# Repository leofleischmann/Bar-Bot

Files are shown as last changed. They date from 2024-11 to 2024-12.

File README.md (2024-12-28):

# Bar-Bot
Automatic Cocktail Maker (Work in Progress)

Project startet on 17th November 2024

This is my take on the Automatic Bartender Robot (original: https://github.com/sidlauskaslukas/barbot/tree/master?tab=readme-ov-file)

# Details
- You can freely decide which drink you want to put on which position. Then you can configure the drink and location in the webserver. (/config)
- You can easily create new recipes and manage your existing ones. (/rezepte)
- You can decide what drink is made with a click of a button. The available recipes are shown in green, while the other ones are red. You can see details on why a recipe is not available.
- Additionally you can see the contents of a recipe with the "?" icon
- Chancing location of drinks is as easy as it gets. Just set the name of your drink and the position.
- Adding new recipes is also very easy. Just select the drink and the quantity, and a file with the instructions for the esp is automatically created.
- When Bottles are reordered, it still works perfectly, as long as you define the new locations on the /config page

# Technical Details
The ESP has minimal code on it. It only takes 2 commands.
- move to position x and
- activate servo, hold for x ms, then go back
The Raspberry Pi takes the heavy lifting, by sending the right commands to the ESP

# Already done:
- All parts are assembled (except liquor holding and pouring construction)
- Project almost compleately digitalized for easyer testing, troubleshooting ect. (3D files, ESP32 emulators...)
- Raspberry Pi Server programmed and functional
- ESP32 Code functional and taking commands from the Raspberry Pi
- Basic Web-Interface for testing purposes.
- Software for the Raspberry Pi and ESP32
- Hardware testing
- Parameter tuning
- User Interface
- Fully functional Web interface to configure, edit, add, remove recipes and drinks with ther corresponding position
- (Done at 22th November 2024)

# Currently working on:
- Woodwork
- Final Adjustments

# Total Hardware cost (not including 3D printing material): to much

# Here are a few images
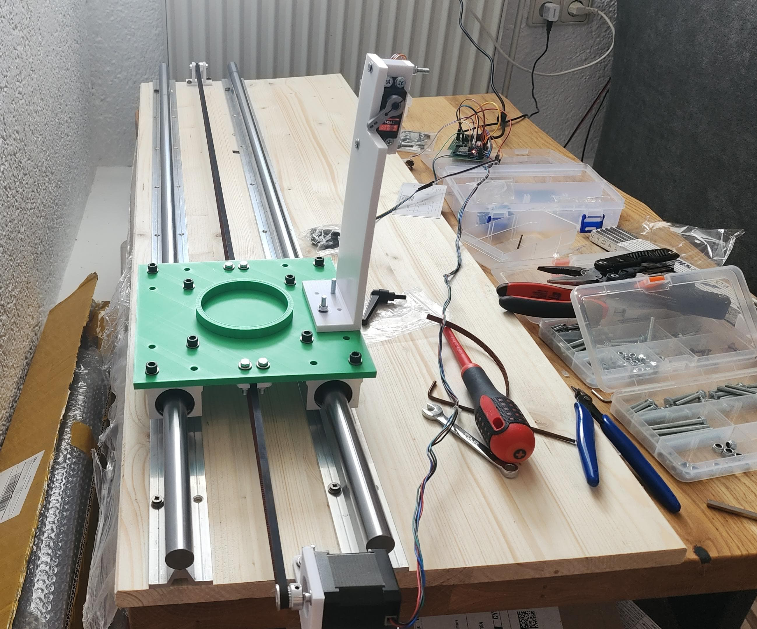
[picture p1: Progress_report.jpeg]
As of 22th November 2024

As of 22th November 2024

# Installation on the Raspberry Pi
- Simply copy the Repo on your Raspberry Pi
- Make sure Port 5001 and 5002 are not in use
- Create a service that starts the server.py script automatically
- You can now find the webserver on port 5001.
- When no Wifi is enabled, a HotSpot is created named "barbot" with password "12345678". You can connect and then configure a new Wifi on Port 5002.
- Have Fun :)

# About the Website:
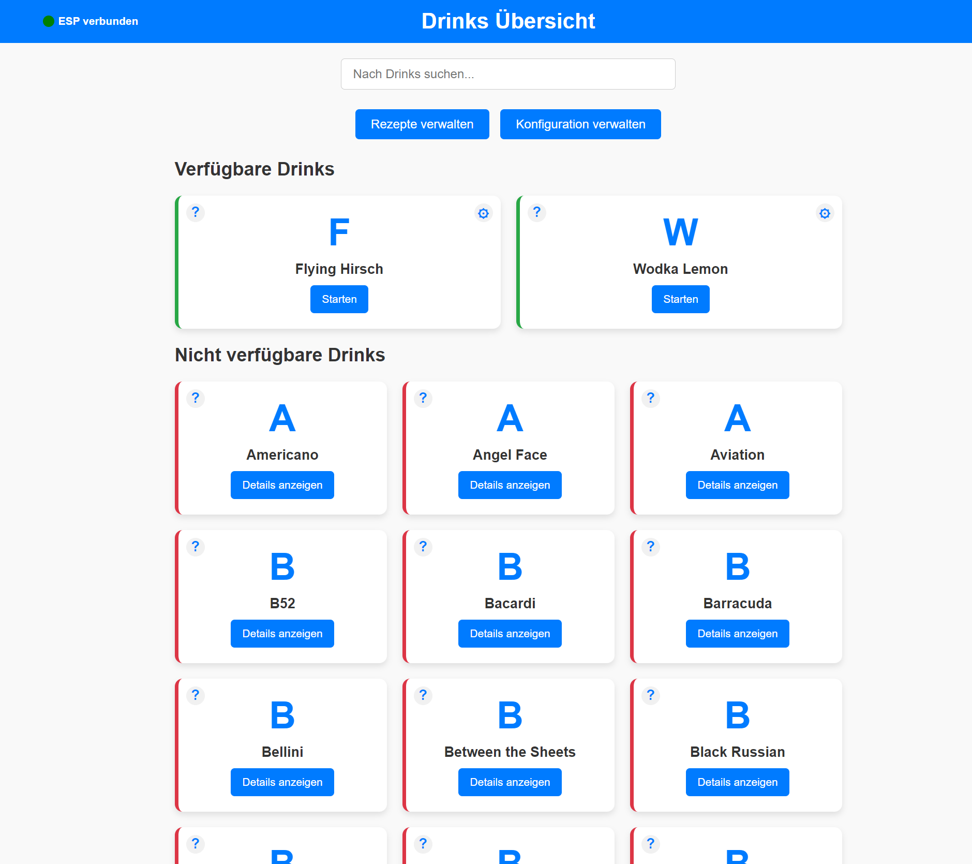
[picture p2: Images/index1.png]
index1.html

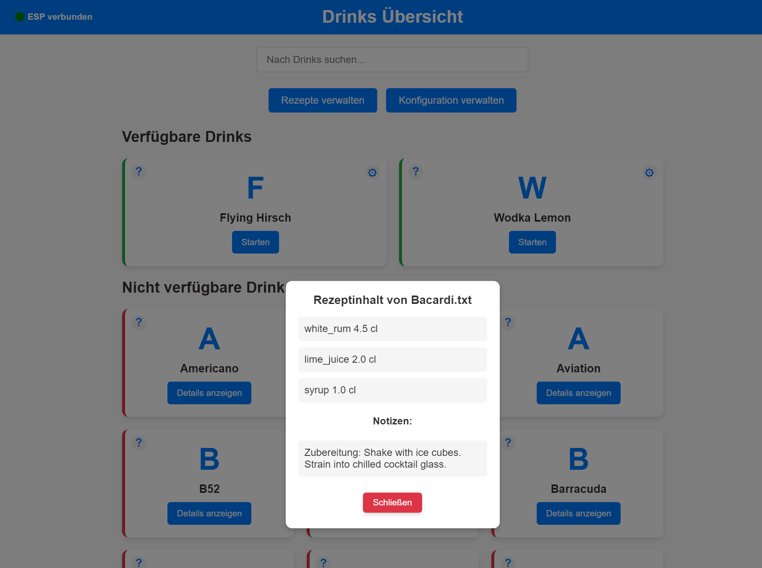
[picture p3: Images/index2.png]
index2.html

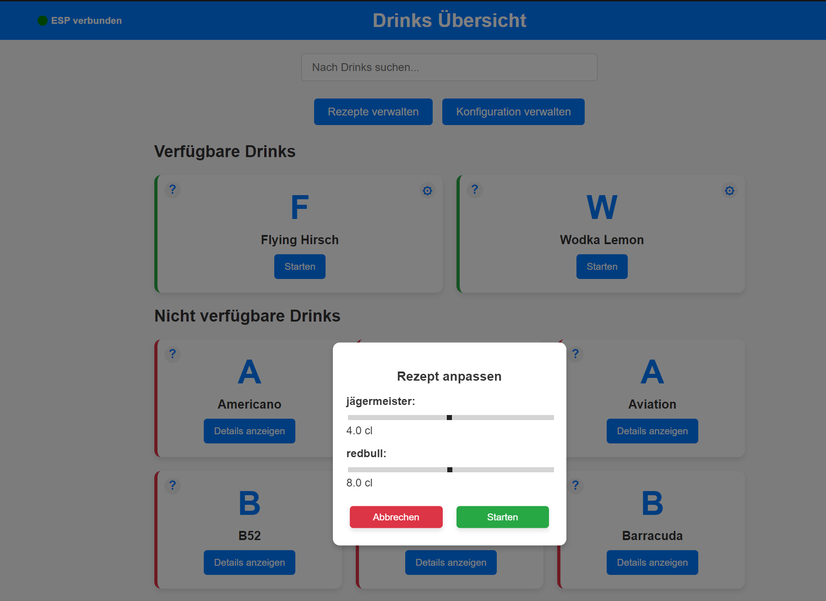
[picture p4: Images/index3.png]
index3.html

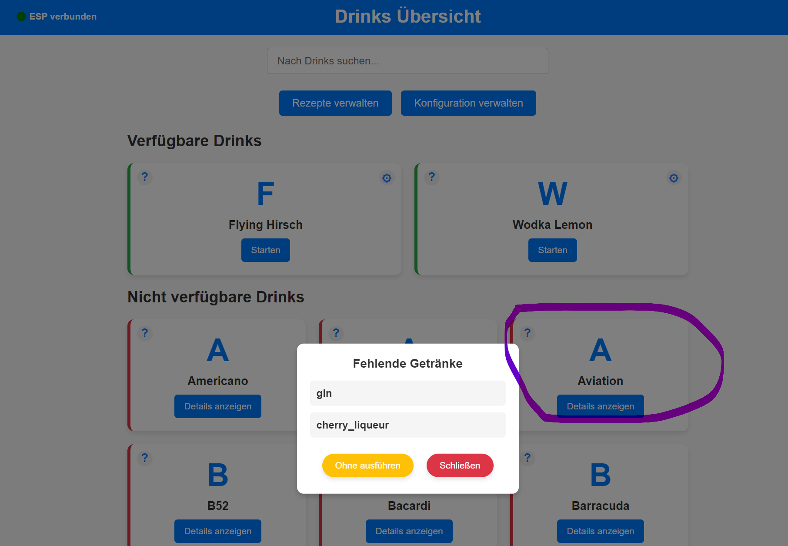
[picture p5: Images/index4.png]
index4.html

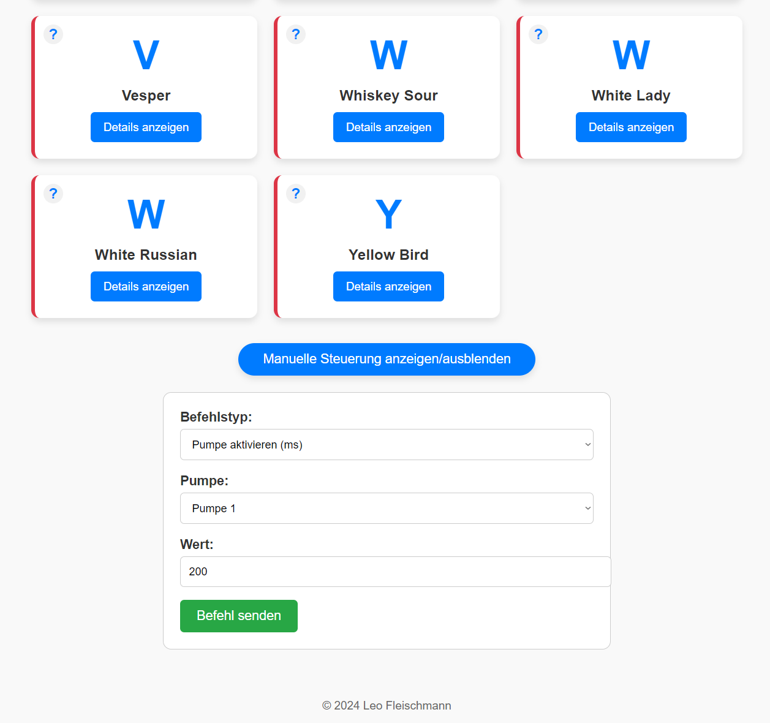
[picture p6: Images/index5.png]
index5.html

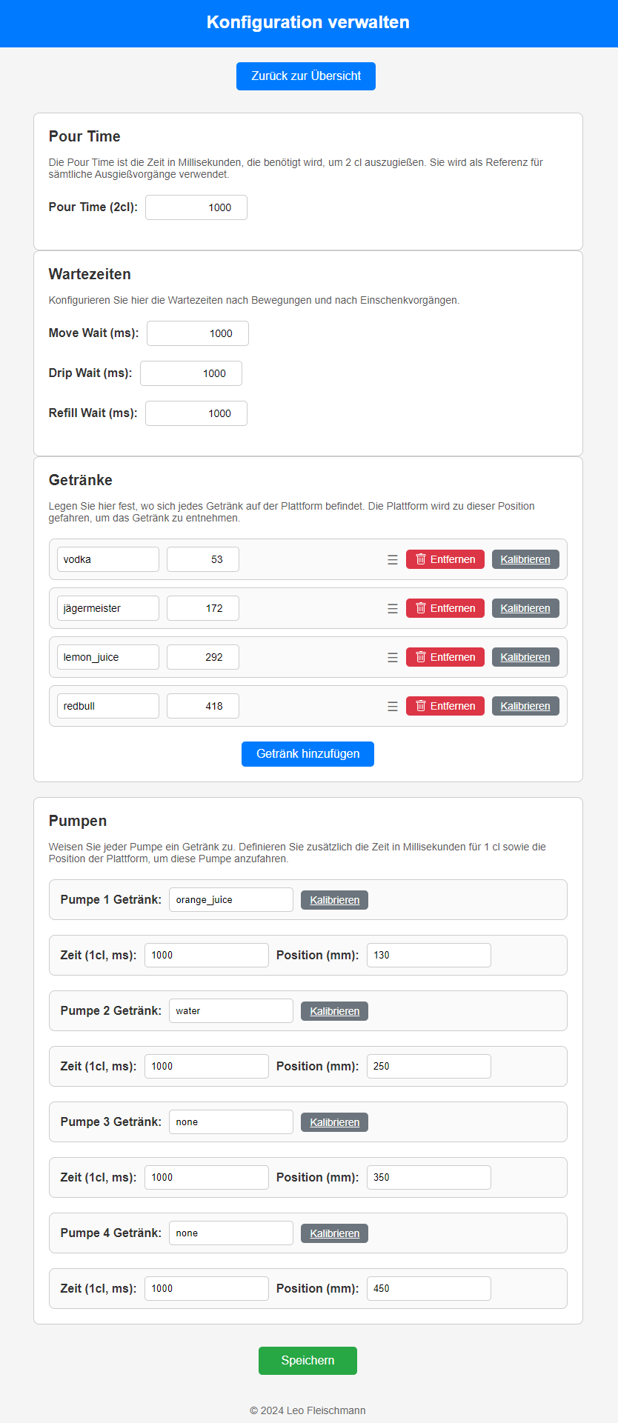
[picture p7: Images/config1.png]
config1.html

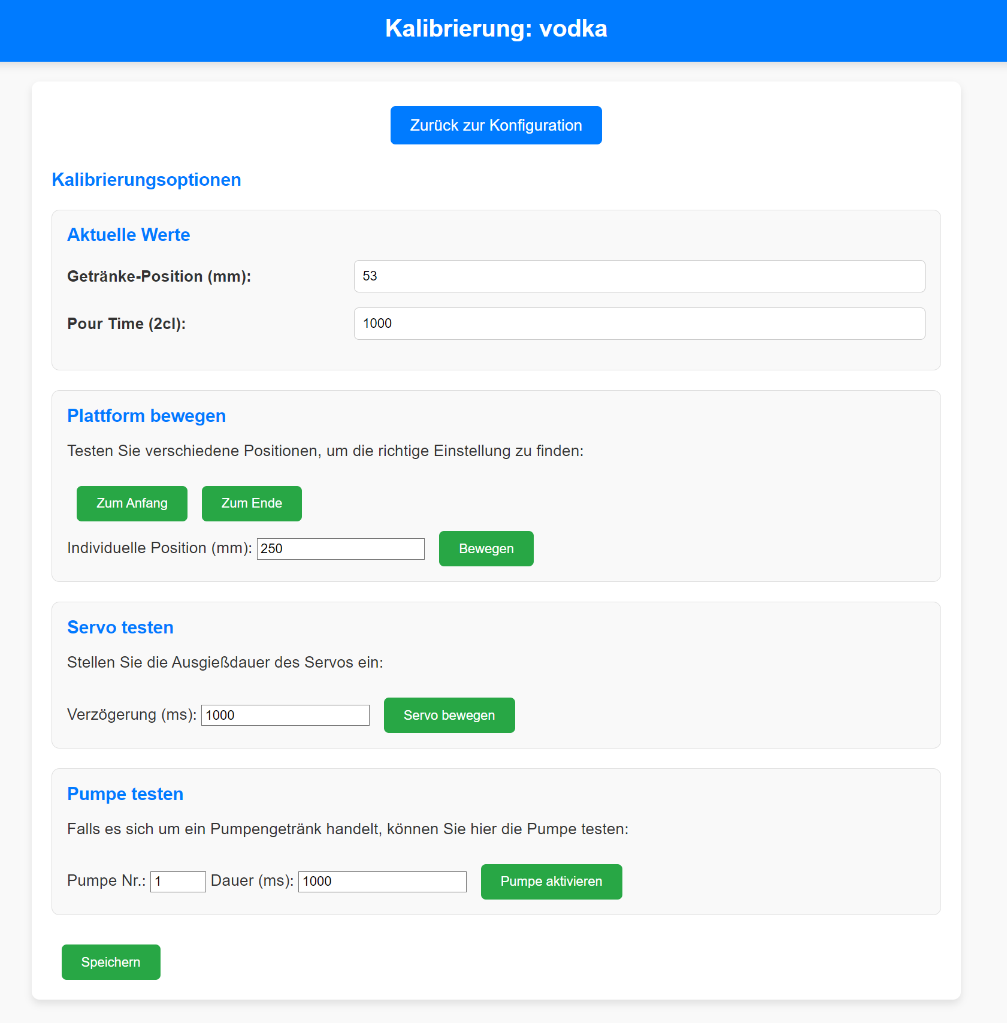
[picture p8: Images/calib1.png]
calib1.html

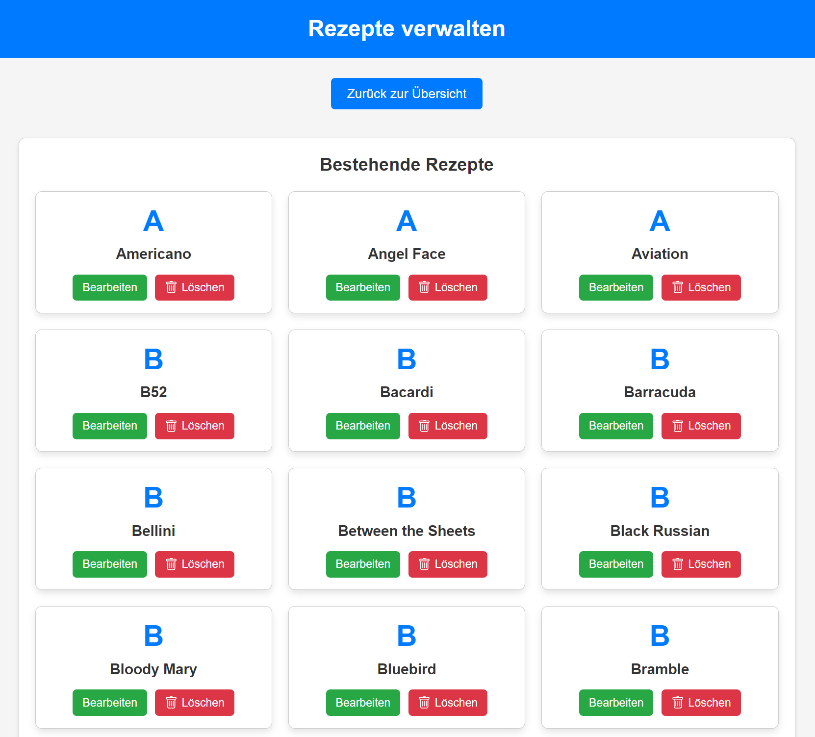
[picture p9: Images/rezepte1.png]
rezepte1.html

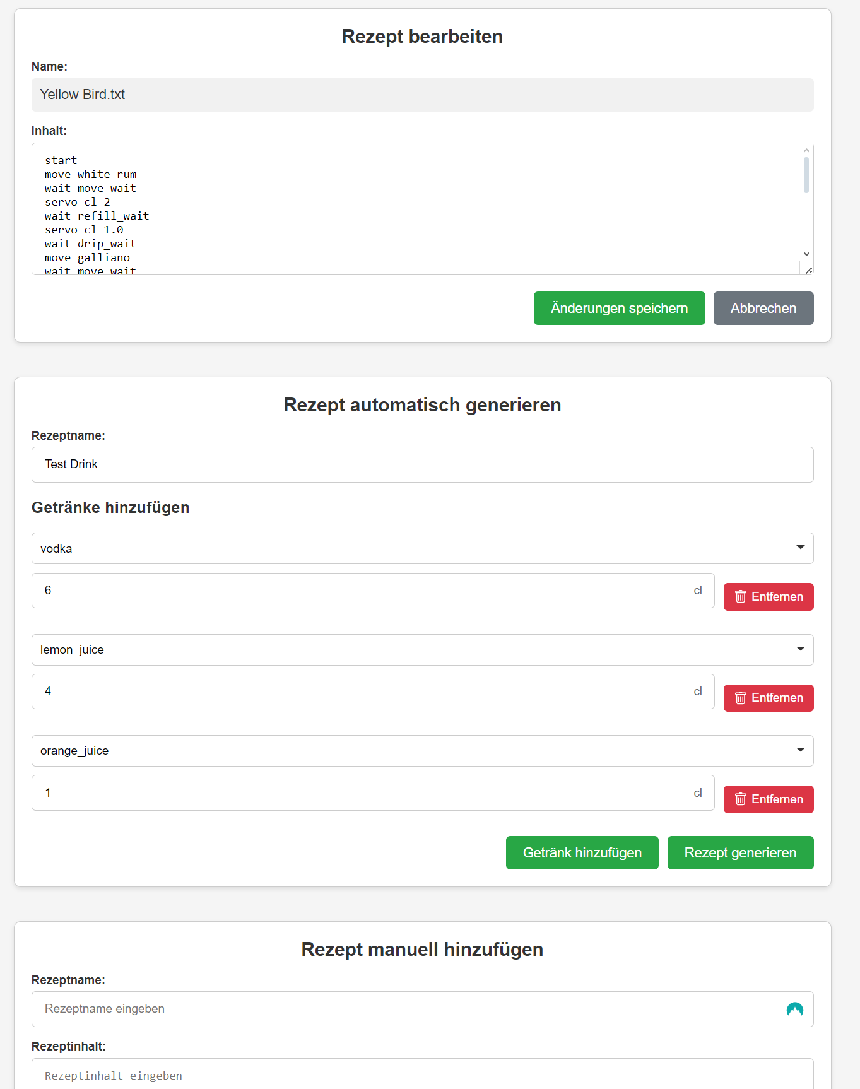
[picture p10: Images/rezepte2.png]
rezepte2.html


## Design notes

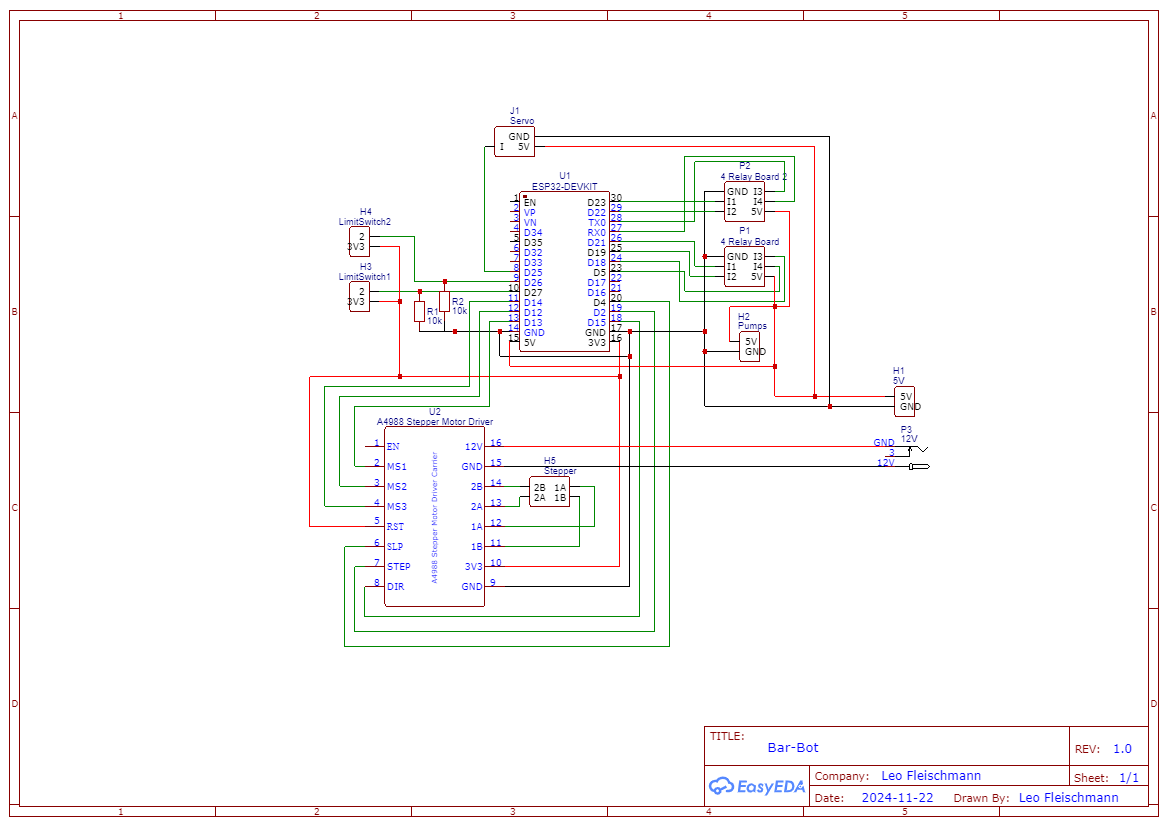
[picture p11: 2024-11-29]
Schematic_Bartender.png

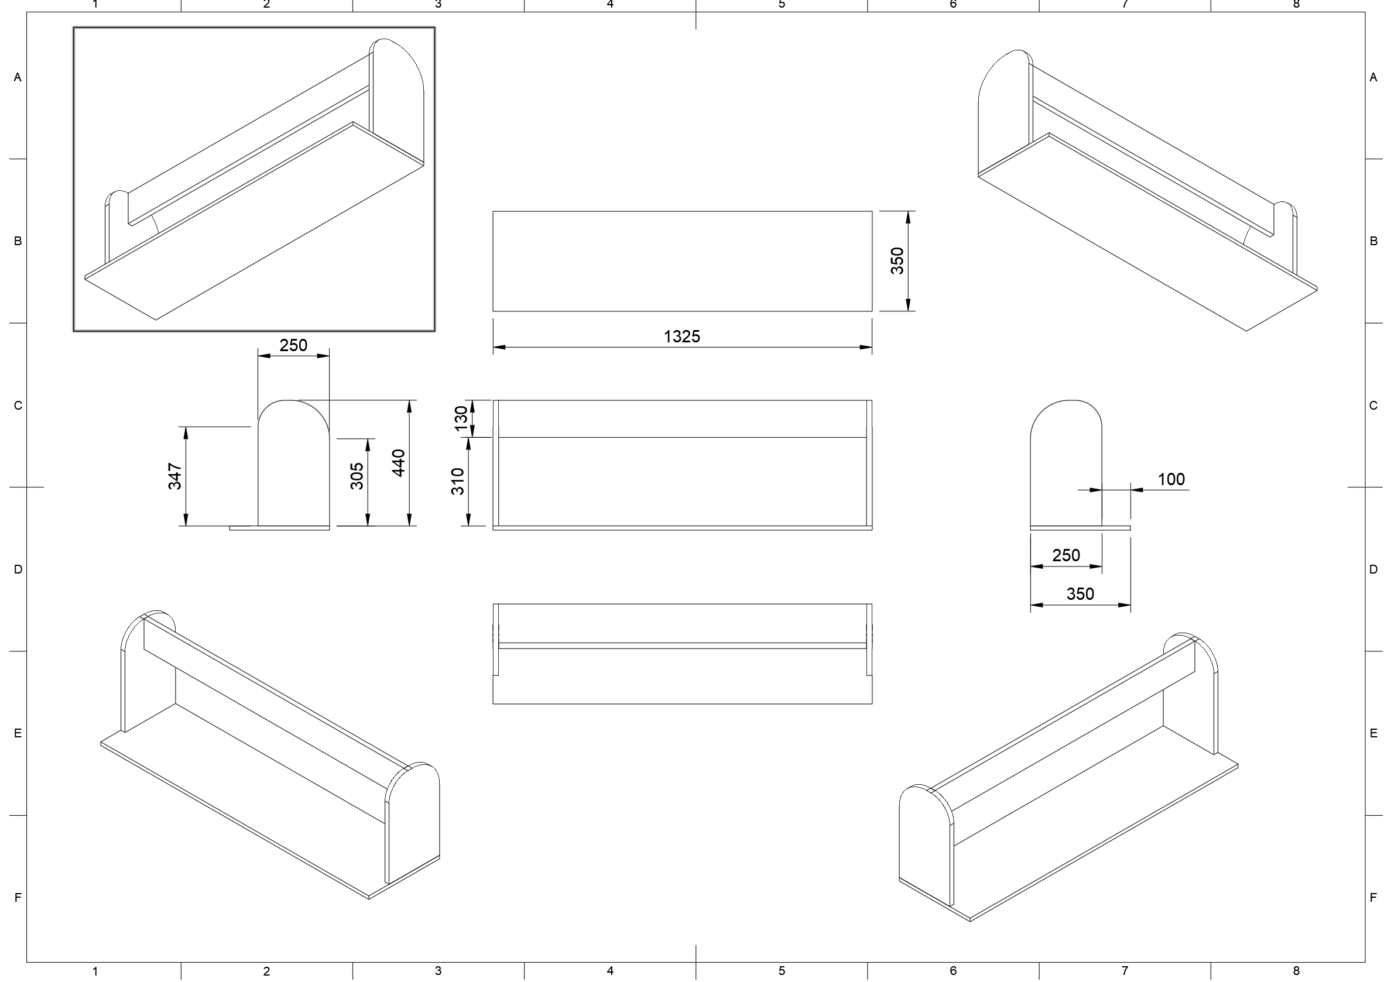
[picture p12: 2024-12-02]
wood.png

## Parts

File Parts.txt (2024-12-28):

Linearführung https://amzn.eu/d/bfyXzXN (1)

Stepper Motor https://amzn.eu/d/i8ZBtZB (1)

Motor Driver https://amzn.eu/d/ecC7P9F (1)

Zahnscheibe https://amzn.eu/d/2rBOimG (2)

Taster https://amzn.eu/d/abpwZf0 (2)

Riemen https://amzn.eu/d/0mO7GU6 (1)

ESP32 https://amzn.eu/d/cdE9kyt (1)

Power Supply https://amzn.eu/d/2pyoxIf (1)

Servo Motor https://amzn.eu/d/6Y2BayV (1)

Dispenser https://amzn.eu/d/ecce646 (9)

Dispenser holder https://amzn.eu/d/dLIQ1ra (9)

Belt https://amzn.eu/d/36YHfLi

Pumps https://amzn.eu/d/5XPfOpe

Pumps pipe https://amzn.eu/d/5c9iQf6

Power Supply https://amzn.eu/d/cTUPZvf

Woodwork: 50€

Diverse Screws

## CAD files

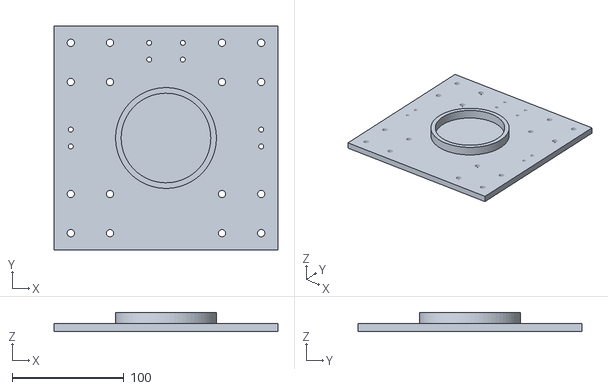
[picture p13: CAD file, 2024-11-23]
STL Files/Platform.stl
200.0 x 200.0 x 17.0

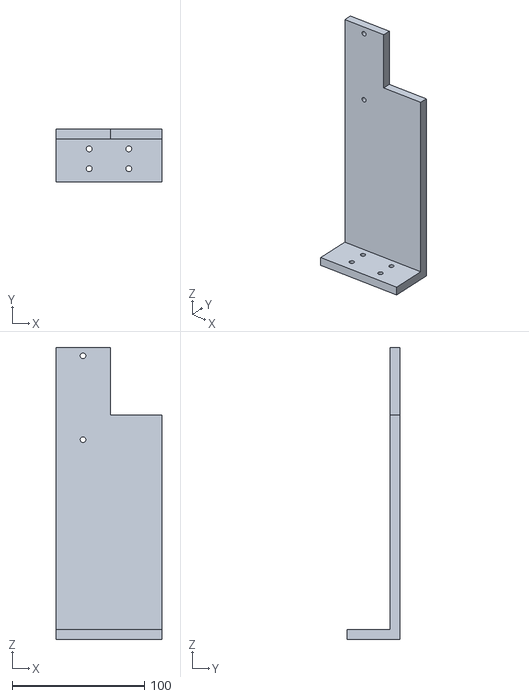
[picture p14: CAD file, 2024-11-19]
STL Files/ServoHalter.stl
80.0 x 40.0 x 221.0

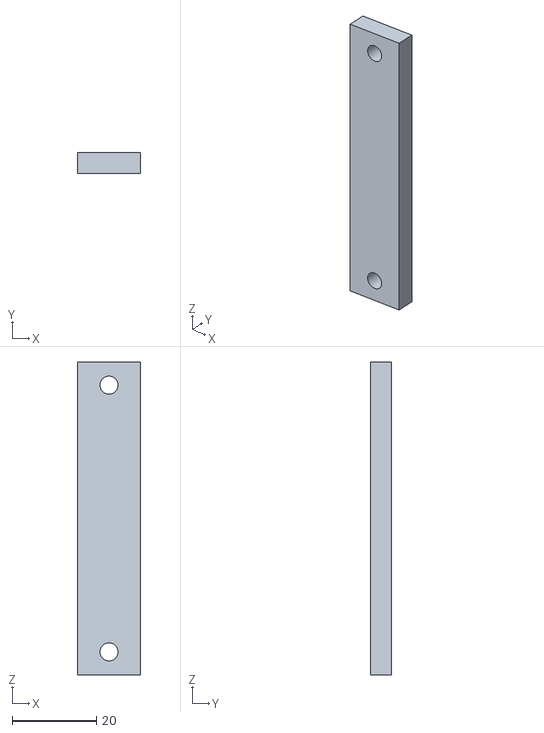
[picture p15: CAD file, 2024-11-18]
STL Files/ServohalterPlatte.stl
15.0 x 5.00 x 74.4

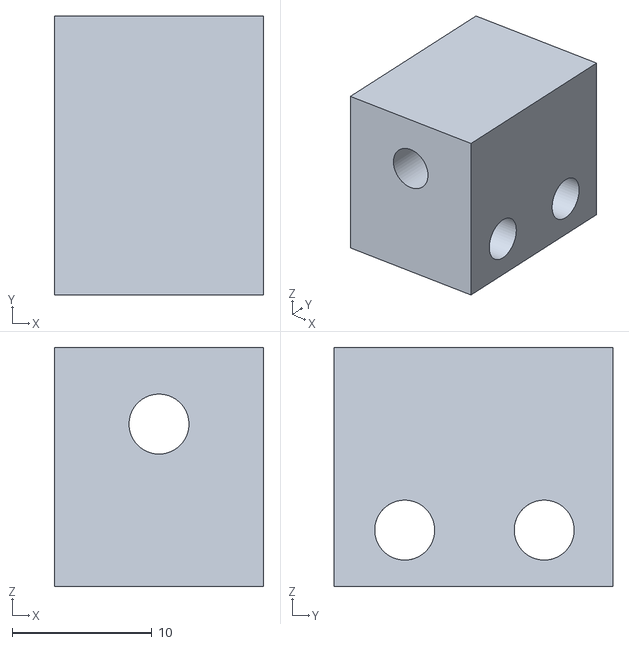
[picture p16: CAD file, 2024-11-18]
STL Files/ServohalterBlock.stl
15.0 x 20.0 x 17.1

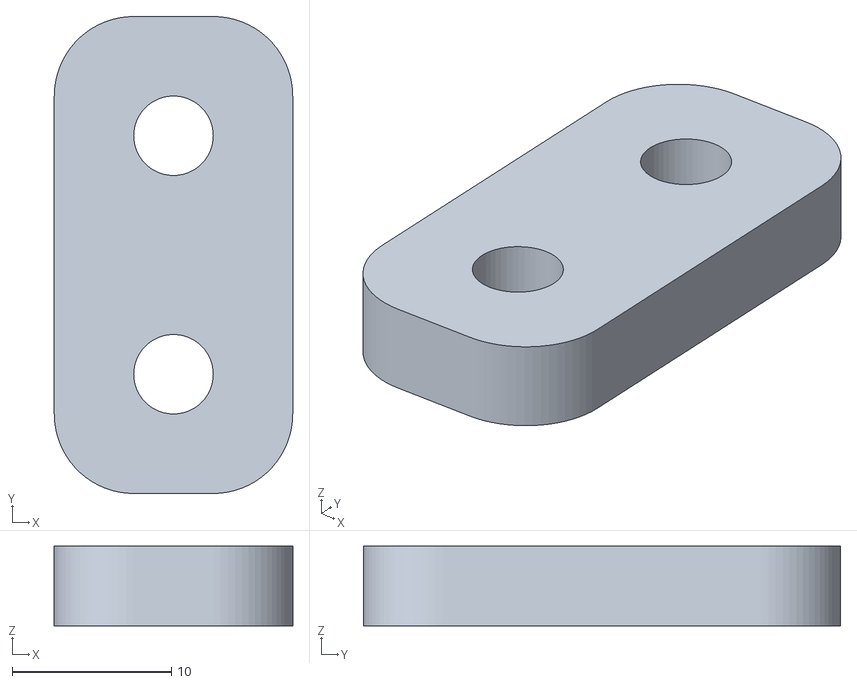
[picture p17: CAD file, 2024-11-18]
STL Files/Riemenklemme.stl
15.0 x 30.0 x 5.00

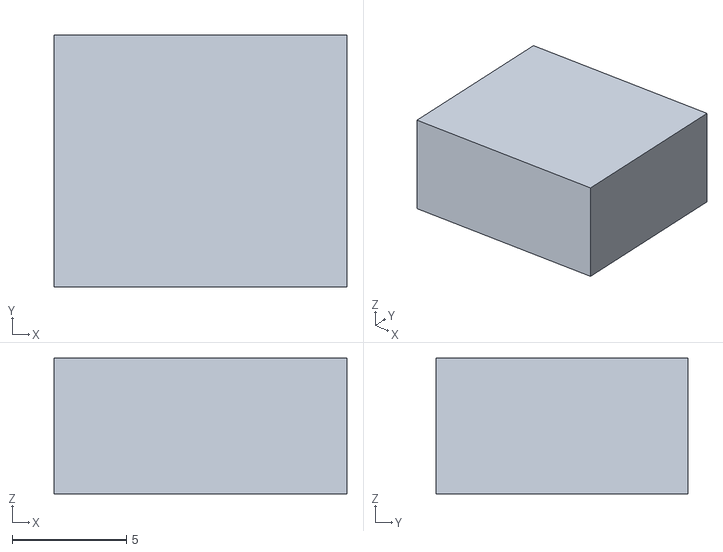
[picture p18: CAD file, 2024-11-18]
STL Files/Tasterhalter.stl
12.8 x 11.0 x 5.94

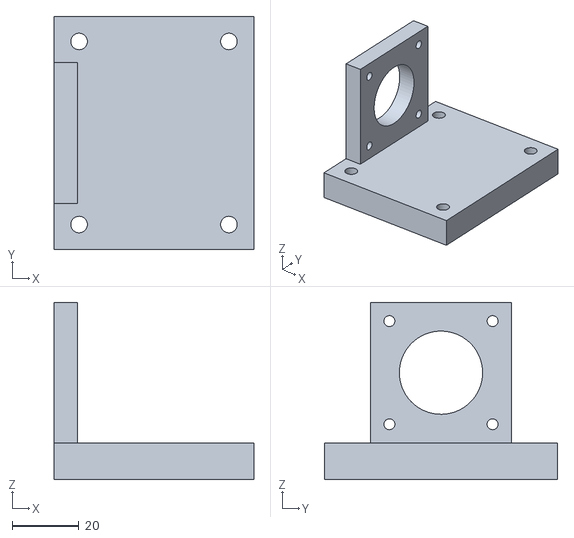
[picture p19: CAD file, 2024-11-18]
STL Files/StepperMount.stl
60.0 x 70.0 x 53.3

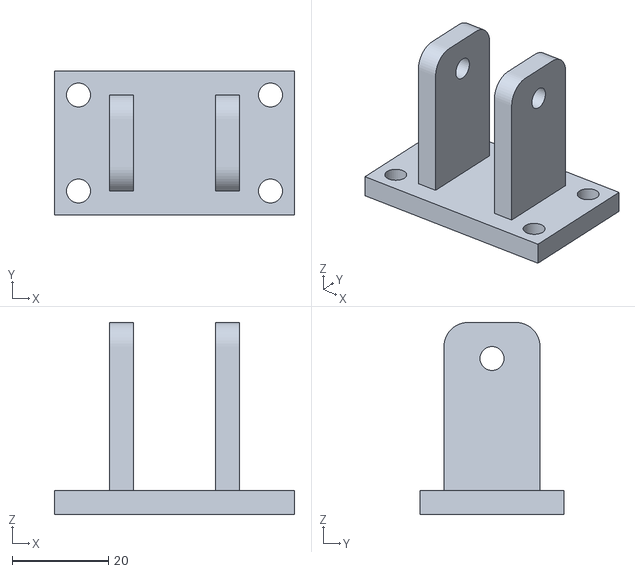
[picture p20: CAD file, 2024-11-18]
STL Files/WheelMount.stl
50.0 x 30.0 x 40.0

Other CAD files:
AutoBarTender_constructed v16.f3d

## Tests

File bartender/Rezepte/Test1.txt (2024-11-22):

start
move gin
servo cl 1
wait 4000
servo ms 3000
wait 2000
done

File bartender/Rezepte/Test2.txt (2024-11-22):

start
move vodka
wait 500
servo cl 1.0
wait 1000
move gin
wait 500
servo cl 2.0
wait 1000
move rum
wait 500
servo cl 2
wait 5000
servo cl 1.0
wait 1000
move 10
done

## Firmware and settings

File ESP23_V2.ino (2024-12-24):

#include <WiFi.h>
#include <HTTPClient.h>
#include <ArduinoOTA.h>
#include <AccelStepper.h>
#include <ESP32Servo.h>
#include <ArduinoJson.h>

// Pin Definitions
#define DIR_PIN 15
#define STEP_PIN 2
#define LIMIT_SWITCH1_PIN 27
#define LIMIT_SWITCH2_PIN 26
#define SLEEP_PIN 4
#define SERVO_PIN 25

// Servo Steps definition (all active for 1/16)
#define MS1 13
#define MS2 12
#define MS3 14

#define PUMP1_PIN 21
#define PUMP2_PIN 19
#define PUMP3_PIN 18
#define PUMP4_PIN 5

struct Pump {
    uint8_t pin;
    bool active;
    unsigned long start;
    unsigned long duration;
};

Pump pumps[4] = {
    {PUMP1_PIN, false, 0, 0},
    {PUMP2_PIN, false, 0, 0},
    {PUMP3_PIN, false, 0, 0},
    {PUMP4_PIN, false, 0, 0}
};

AccelStepper stepper(AccelStepper::DRIVER, STEP_PIN, DIR_PIN);
Servo myServo;
int servoDelay = 1000;

const char* ssid = "ssid";
const char* password = "pass";

IPAddress local_IP(192, 168, 2, 236);
IPAddress gateway(192, 168, 2, 1);
IPAddress subnet(255, 255, 255, 0);
IPAddress dns(192, 168, 2, 40);

const int moveMaxSpeed = 6000;
const int moveAcceleration = 1200;
const int calibMaxSpeed = 2600;
const int maxMillimeters = 1200;

long maxSteps = 0;
long currentPosition = 0;

void createJsonResponse(const char* status, const char* message, String &response) {
    StaticJsonDocument<200> doc;
    doc["status"] = status;
    doc["message"] = message;
    serializeJson(doc, response);
}

void setup() {
    Serial.begin(115200);
    Serial.println("DEBUG: ESP32 Initialisierung gestartet");

    pinMode(LIMIT_SWITCH1_PIN, INPUT);
    pinMode(LIMIT_SWITCH2_PIN, INPUT);
    pinMode(SLEEP_PIN, OUTPUT);
    digitalWrite(SLEEP_PIN, LOW);

    pinMode(MS1, OUTPUT);
    pinMode(MS2, OUTPUT);
    pinMode(MS3, OUTPUT);
    digitalWrite(MS1, HIGH);
    digitalWrite(MS2, HIGH);
    digitalWrite(MS3, HIGH);

    for (int i = 0; i < 4; i++) {
        pinMode(pumps[i].pin, OUTPUT);
        digitalWrite(pumps[i].pin, HIGH);
        pumps[i].active = false;
    }

    stepper.setMaxSpeed(moveMaxSpeed);
    stepper.setAcceleration(moveAcceleration);

    myServo.attach(SERVO_PIN);
    myServo.write(90);

    connectToWiFi();
    setupOTA();

    calibratePlatform();
    moveToMM(maxMillimeters / 2);

    Serial.println("DEBUG: Setup abgeschlossen.");
}

void loop() {
    ArduinoOTA.handle();
    handlePumpDurations();
    handleSerialCommands();
}

void handlePumpDurations() {
    unsigned long currentMillis = millis();
    for (int i = 0; i < 4; i++) {
        if (pumps[i].active && (currentMillis - pumps[i].start >= pumps[i].duration)) {
            // Pumpe automatisch deaktivieren
            pumps[i].active = false;
            digitalWrite(pumps[i].pin, HIGH);
            Serial.printf("DEBUG: Pumpe %d deaktiviert.\n", i + 1);
        }
    }
}

void handleSerialCommands() {
    static String inputString = "";
    while (Serial.available() > 0) {
        char c = (char)Serial.read();
        if (c == '\n') {
            if (inputString.length() > 0) {
                processSerialCommand(inputString);
                inputString = "";
            }
        } else {
            inputString += c;
        }
    }
}

void processSerialCommand(String commandStr) {
    StaticJsonDocument<200> doc;
    DeserializationError error = deserializeJson(doc, commandStr);
    if (error) {
        Serial.println("DEBUG: Ungültiges JSON ignoriert.");
        return;
    }

    const char* cmd = doc["command"];
    if (!cmd) return;

    String response;

    if (strcmp(cmd, "move") == 0) {
        int targetMM = doc["position"];
        Serial.printf("DEBUG: Bewegung zu %d mm angefordert.\n", targetMM);
        moveToMM(targetMM);

        // Jetzt nur JSON, keine weiteren Ausgaben danach
        createJsonResponse("success", "Bewegung abgeschlossen", response);
        Serial.println(response);

    } else if (strcmp(cmd, "servo") == 0) {
        int delayTime = doc["delay"];
        if (delayTime < 0) {
            createJsonResponse("error", "Ungültige Verzögerung", response);
            Serial.println(response);
            return; 
        }

        Serial.printf("DEBUG: Servo bewegen (180 Grad), warte %d ms, zurück zu 90 Grad.\n", delayTime);
        servoDelay = delayTime;
        myServo.write(180);
        delay(180);
        delay(servoDelay);
        myServo.write(90);
        delay(180);

        createJsonResponse("success", "Servo-Bewegung abgeschlossen", response);
        Serial.println(response);

    } else if (strcmp(cmd, "pump") == 0) {
        int pumpNumber = doc["pump"];
        int duration = doc["duration"];
        if (pumpNumber < 1 || pumpNumber > 4 || duration <= 0) {
            createJsonResponse("error", "Ungültige Pumpennummer oder Dauer", response);
            Serial.println(response);
            return;
        }

        // Debug vor JSON
        Serial.printf("DEBUG: Pumpe %d wird für %d ms aktiviert.\n", pumpNumber, duration);

        // Pumpe aktivieren ohne späteres delay oder Ausgabe
        Pump &pump = pumps[pumpNumber - 1];
        if (pump.active) {
            Serial.println("DEBUG: Pumpe ist bereits aktiv, ignoriere Aktivierung.");
            createJsonResponse("error", "Pumpe bereits aktiv", response);
            Serial.println(response);
            return;
        }

        pump.active = true;
        pump.start = millis();
        pump.duration = duration;
        digitalWrite(pump.pin, LOW);

        // Jetzt JSON ausgeben, danach keine Ausgaben mehr
        createJsonResponse("success", "Pumpe aktiviert", response);
        Serial.println(response);

        // KEINE weitere Ausgabe nach JSON!

    } else if (strcmp(cmd, "status") == 0) {
        // Keine Debug-Ausgabe, direkt JSON
        StaticJsonDocument<256> statusDoc;
        statusDoc["status"] = "online";
        JsonArray pumpStatuses = statusDoc.createNestedArray("pumps");
        for (int i = 0; i < 4; i++) {
            JsonObject pumpObj = pumpStatuses.createNestedObject();
            pumpObj["pumpNumber"] = i + 1;
            pumpObj["active"] = pumps[i].active;
            pumpObj["remainingTime"] = pumps[i].active ? (pumps[i].duration - (millis() - pumps[i].start)) : 0;
        }
        serializeJson(statusDoc, response);
        Serial.println(response);

        // Keine weitere Ausgabe nach JSON!
    }
}

void connectToWiFi() {
  Serial.println("DEBUG: Statische IP konfigurieren...");
  if (!WiFi.config(local_IP, gateway, subnet, dns)) {
    Serial.println("DEBUG: Fehler: Statische IP konnte nicht konfiguriert werden!");
  } else {
    Serial.println("DEBUG: Statische IP erfolgreich konfiguriert.");
  }

  Serial.printf("DEBUG: Verbinde mit WLAN '%s'...\n", ssid);
  WiFi.begin(ssid, password);
  while (WiFi.status() != WL_CONNECTED) {
    delay(500);
  }
  Serial.printf("DEBUG: WLAN verbunden! IP-Adresse: %s\n", WiFi.localIP().toString().c_str());
}

void setupOTA() {
  ArduinoOTA.setHostname("ESP32-Stepper");

  ArduinoOTA.onStart([]() {
    String type = (ArduinoOTA.getCommand() == U_FLASH) ? "Sketch" : "SPIFFS";
    Serial.printf("DEBUG: OTA-Update gestartet: %s\n", type.c_str());
  });
  ArduinoOTA.onEnd([]() {
    Serial.println("DEBUG: OTA-Update abgeschlossen.");
  });
  ArduinoOTA.onProgress([](unsigned int progress, unsigned int total) {
    Serial.printf("DEBUG: OTA-Fortschritt: %u%%\r", (progress / (total / 100)));
  });
  ArduinoOTA.onError([](ota_error_t error) {
    Serial.printf("DEBUG: OTA-Fehler [%u]: ", error);
    if (error == OTA_AUTH_ERROR) Serial.println("DEBUG: Authentifizierungsfehler");
    else if (error == OTA_BEGIN_ERROR) Serial.println("DEBUG: Beginn-Fehler");
    else if (error == OTA_CONNECT_ERROR) Serial.println("DEBUG: Verbindungsfehler");
    else if (error == OTA_RECEIVE_ERROR) Serial.println("DEBUG: Empfangsfehler");
    else if (error == OTA_END_ERROR) Serial.println("DEBUG: Ende-Fehler");
  });

  ArduinoOTA.begin();
  Serial.println("DEBUG: OTA eingerichtet.");
}

void enableDriver() {
  Serial.println("DEBUG: Treiber aktivieren...");
  digitalWrite(SLEEP_PIN, HIGH);
}

void disableDriver() {
  Serial.println("DEBUG: Treiber deaktivieren...");
  digitalWrite(SLEEP_PIN, LOW);
}

void calibratePlatform() {
    Serial.println("DEBUG: Kalibrierung: Bewege zu Endschalter 1...");
    enableDriver();

    stepper.setSpeed(-calibMaxSpeed);

    // Starte die Kalibrierungsfahrt in Richtung Endschalter 1
    while (true) {
        // So lange der Schalter NICHT gedrückt ist (LOW), weiterfahren
        if (digitalRead(LIMIT_SWITCH1_PIN) == LOW) {
            stepper.runSpeed();
        } else {
            // Sobald der Pin HIGH meldet, kurz warten, um Prellen zu vermeiden
            delay(100); 
            // Jetzt erneut prüfen, ob der Schalter immer noch HIGH ist
            if (digitalRead(LIMIT_SWITCH1_PIN) == HIGH) {
                // Debounce-Bestätigung: Schalter wirklich ausgelöst
                break;
            }
        }
    }

    // Schritt-Motor anhalten
    stepper.stop();
    // Bezugsposition auf 0 setzen
    stepper.setCurrentPosition(0);
    Serial.println("DEBUG: Kalibrierung: Endschalter 1 erreicht. Position auf 0 gesetzt.");

    Serial.println("DEBUG: Kalibrierung: Bewege zu Endschalter 2...");
    stepper.setSpeed(calibMaxSpeed);

    // Fahre in die andere Richtung bis Endschalter 2
    while (true) {
        if (digitalRead(LIMIT_SWITCH2_PIN) == LOW) {
            stepper.runSpeed();
        } else {
            delay(100);
            if (digitalRead(LIMIT_SWITCH2_PIN) == HIGH) {
                break;
            }
        }
    }

    stepper.stop();
    // Maximale Schritte speichern
    maxSteps = stepper.currentPosition();
    Serial.printf("DEBUG: Kalibrierung abgeschlossen. Maximale Schritte: %ld\n", maxSteps);

    disableDriver();
}


void moveToMM(int targetMM) {
  if (targetMM < 0 || targetMM > maxMillimeters) {
    Serial.printf("DEBUG: Ungültige Position: %d mm (Erlaubt: 0-%d mm)\n", targetMM, maxMillimeters);
    return;
  }

  long steps = map(targetMM, 0, maxMillimeters, 0, maxSteps);
  Serial.printf("DEBUG: Bewege Plattform zu %d mm (%ld Schritte)...\n", targetMM, steps);

  enableDriver();
  stepper.moveTo(steps);

  while (stepper.distanceToGo() != 0) {
    stepper.run();
  }

  currentPosition = stepper.currentPosition();
  Serial.printf("DEBUG: Position erreicht: %d mm (%ld Schritte).\n", targetMM, currentPosition);

  disableDriver();
}

void activatePump(int pumpNumber, int duration) {
    // Diese Funktion aktiviert die Pumpe sofort und vertraut darauf,
    // dass handlePumpDurations() sie später automatisch ausschaltet.
    Pump &pump = pumps[pumpNumber - 1];
    pump.active = true;
    pump.start = millis();
    pump.duration = duration;
    digitalWrite(pump.pin, LOW);
    // Keine weiteren Ausgaben nach der JSON-Antwort!
}

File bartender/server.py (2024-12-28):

import os
import json
import time
import serial
from flask import Flask, jsonify, render_template, request, redirect, url_for
from threading import Thread, Lock
import serial.tools.list_ports
import subprocess

app = Flask(__name__)

RECIPE_FOLDER = "Rezepte"
CONFIG_FILE = "config.json"

# SERIAL_PORT wird nicht mehr fest vorgegeben, sondern automatisch ermittelt
BAUDRATE = 115200

ser = None
esp_connected = False
serial_lock = Lock()

# **Globale Variablen Definieren**
active_recipe = None
is_running = False
current_progress = 0

current_recipe_notes = {"recipe_name": "", "notes": []}
current_recipe_notes_lock = Lock()

def find_esp_port():
    ports = serial.tools.list_ports.comports()
    for port in ports:
        manufacturer = port.manufacturer or "Unbekannt"
        product = port.product or "Unbekannt"
        print(f"Prüfe Port: {port.device} - Hersteller: {manufacturer} - Produkt: {product}")
        if port.device.startswith("/dev/ttyUSB"):
            print(f"ESP (vermutet) an Port {port.device}")
            return port.device
    return None

def init_serial():
    global ser, esp_connected
    max_retries = 10
    retry_interval = 10  # in Sekunden

    for attempt in range(max_retries):
        esp_port = find_esp_port()
        if esp_port is None:
            print(f"Kein ESP gefunden. Warte {retry_interval} Sekunden und versuche es erneut... ({attempt+1}/{max_retries})")
            time.sleep(retry_interval)
            continue

        try:
            ser = serial.Serial(esp_port, BAUDRATE, timeout=2)
            esp_connected = True
            print(f"ESP verbunden an {esp_port}")
            return
        except serial.SerialException as e:
            print(f"ESP nicht verbunden: {e}")
            esp_connected = False
            ser = None

        print(f"Verbindung fehlgeschlagen. Warte {retry_interval} Sekunden und versuche es erneut... ({attempt+1}/{max_retries})")
        time.sleep(retry_interval)

    print("Nach mehreren Versuchen konnte keine Verbindung zum ESP hergestellt werden.")

def is_wifi_connected():
    """
    Gibt True zurück, wenn WLAN verbunden ist, sonst False.
    """
    try:
        # Beispiel: Wenn 'iwgetid' einen ESSID zurückgibt, sind wir verbunden
        result = subprocess.check_output(["iwgetid", "-r"]).decode("utf-8").strip()
        return len(result) > 0
    except Exception:
        return False


def send_command_to_esp(command_dict):
    global ser, esp_connected
    with serial_lock:
        if not esp_connected or ser is None or not ser.is_open:
            return {"status": "error", "message": "ESP nicht verbunden"}

        try:
            cmd_str = json.dumps(command_dict) + "\n"
            ser.write(cmd_str.encode('utf-8'))

            start_time = time.time()
            while True:
                line = ser.readline().decode('utf-8', errors='replace').strip()
                if not line:
                    if time.time() - start_time > 5:
                        return {"status": "error", "message": "Keine Antwort vom ESP"}
                    continue

                # Debug-Zeilen ignorieren
                if line.startswith("DEBUG:"):
                    continue

                # Nur JSON-Linien verarbeiten
                if line.startswith("{"):
                    try:
                        resp = json.loads(line)
                        return resp
                    except json.JSONDecodeError as e:
                        print(f"JSON-Fehler beim Parsen der ESP-Antwort: {e}, empfangene Daten: {line}")
                        return {"status": "error", "message": "Ungültige Antwort vom ESP"}

        except Exception as e:
            print(f"Fehler bei der ESP-Kommunikation: {e}")
            esp_connected = False
            return {"status": "error", "message": "Kommunikationsfehler mit ESP"}

def load_config():
    try:
        with open(CONFIG_FILE, "r") as file:
            return json.load(file)
    except FileNotFoundError:
        print(f"Konfigurationsdatei '{CONFIG_FILE}' nicht gefunden! Erstelle eine neue.")
        return {}
    except json.JSONDecodeError as e:
        print(f"Fehler beim Lesen der Konfigurationsdatei: {e}")
        return {}

def save_config(new_config):
    try:
        # Alte Konfiguration laden
        existing_config = load_config()

        # Geschützte Schlüssel bewahren
        protected_keys = ["wlan_ssid", "wlan_password"]
        for key in protected_keys:
            if key in existing_config and key not in new_config:
                new_config[key] = existing_config[key]

        # Neue Konfiguration speichern
        with open(CONFIG_FILE, "w") as file:
            json.dump(new_config, file, indent=4)
        print("Konfiguration erfolgreich gespeichert.")
    except Exception as e:
        print(f"Fehler beim Speichern der Konfigurationsdatei: {e}")

def check_esp_connection():
    global esp_connected
    if not esp_connected or ser is None or not ser.is_open:
        return False
    with serial_lock:
        try:
            ser.write(b'{"command":"status"}\n')
            line = ser.readline().decode('utf-8').strip()
            if not line:
                return False

            if line.startswith("DEBUG:"):
                start = time.time()
                while line.startswith("DEBUG:"):
                    if time.time() - start > 2:
                        return False
                    line = ser.readline().decode('utf-8').strip()
                    if not line:
                        return False

            if line.startswith("{"):
                try:
                    resp_json = json.loads(line)
                    return resp_json.get("status") == "online"
                except json.JSONDecodeError as e:
                    print(f"JSON-Fehler beim Überprüfen des ESP-Status: {e}, Daten: {line}")
                    return False
            else:
                return False
        except Exception as e:
            print(f"Fehler bei der ESP-Kommunikation: {e}")
            esp_connected = False
            return False
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

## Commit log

2024-11-17 Status after one Day of working on it.
    [AutoBarTender_constructed.f3d]
2024-11-21 Uploaded Raspberry Pi files
2024-11-22 Files for the Raspberry Pi
2024-11-27 Update config.html
    Added the ability to configure pumps
2024-11-28 Update server.py
    added pump functionality
2024-11-28 Update server.py
    updated pump functionality and recipe generation, as well as execution
2024-11-28 Update server.py
    pump and servo differention
2024-11-28 Update index.html
    added manual pump controll
2024-11-28 Update server.py
    bug fixes
    [server.py]
2024-12-02 Updated Fusion File
    [AutoBarTender_constructed v16.f3d]
2024-12-16 Update server.py
    Changed communication between ESP and Raspberry Pi from Wifi to serial
2024-12-24 Update ESP23_V2.ino
    Added Debounce on Limit Switches
2024-12-27 Update server.py
    Thread for init_serial to noch block webserver on startup
